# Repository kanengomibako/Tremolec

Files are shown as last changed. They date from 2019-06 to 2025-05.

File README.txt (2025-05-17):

Tremolec

トレモロを周波数帯域別にかけるというエフェクターです。
製作記事→https://kanengomibako.github.io/pages/00243.html

＜パーツリスト＞
2	220p	[1608] C3, C4
1	4.7n	C10　※DIPフィルムコンデンサ
2	22n	C6, C13　※DIPフィルムコンデンサ
1	47n	C14　※DIPフィルムコンデンサ
1	100n	[3225] C1　※PMLCAP
2	100n	C11, C12　※DIPフィルムコンデンサ
10	100n	[2012] C19, C20, C21, C22, C24, C25, C26, C27, C28, C29
2	330n	C5, C8　※DIPフィルムコンデンサ
2	10u	C2, C15　※SMD電解コンデンサ（直径5mm）
4	10u	[3216] C16, C17, C23, C30
1	100u	C18　※DIP電解コンデンサ
		
1	220R	[2012] R25
2	470R	[2012] R14, R22
8	1k	[2012] R3, R8, R9, R15, R17, R18, R23, R24
5	4.7k	[2012] R5, R7, R10, R30, R32
6	10k	[2012] R4, R6, R31, R33, R34, R35
11	100k	[2012] R11, R12, R13, R16, R19, R20, R21, R26, R27, R28, R29
1	1M	[2012] R2
1	2.2M	[1608] R1
		
5	10kB	RV1, RV2, RV3, RV4, RV5
		
6	LCR0202	U4, U5, U6, U7, U8, U9
		
1	1N4007	D1
2	LED	D2, D3
		
3	OPA1678IDR	U1, U2, U3
1	LP2950L-3.3V	U10
1	LP2950L-5.0V	U11
1	ATmega328P-AU	U12
3	MCP4922-E/SL	U13, U14, U15
		
1	SPST Momentary Push Switch	SW1　※タップスイッチ
1	SPDT ON-ON Toggle Switch	SW2
1	SPDT ON-OFF-ON Toggle Switch	SW3
1	3PDT ON-ON Push Switch	※トゥルーバイパス用スイッチ

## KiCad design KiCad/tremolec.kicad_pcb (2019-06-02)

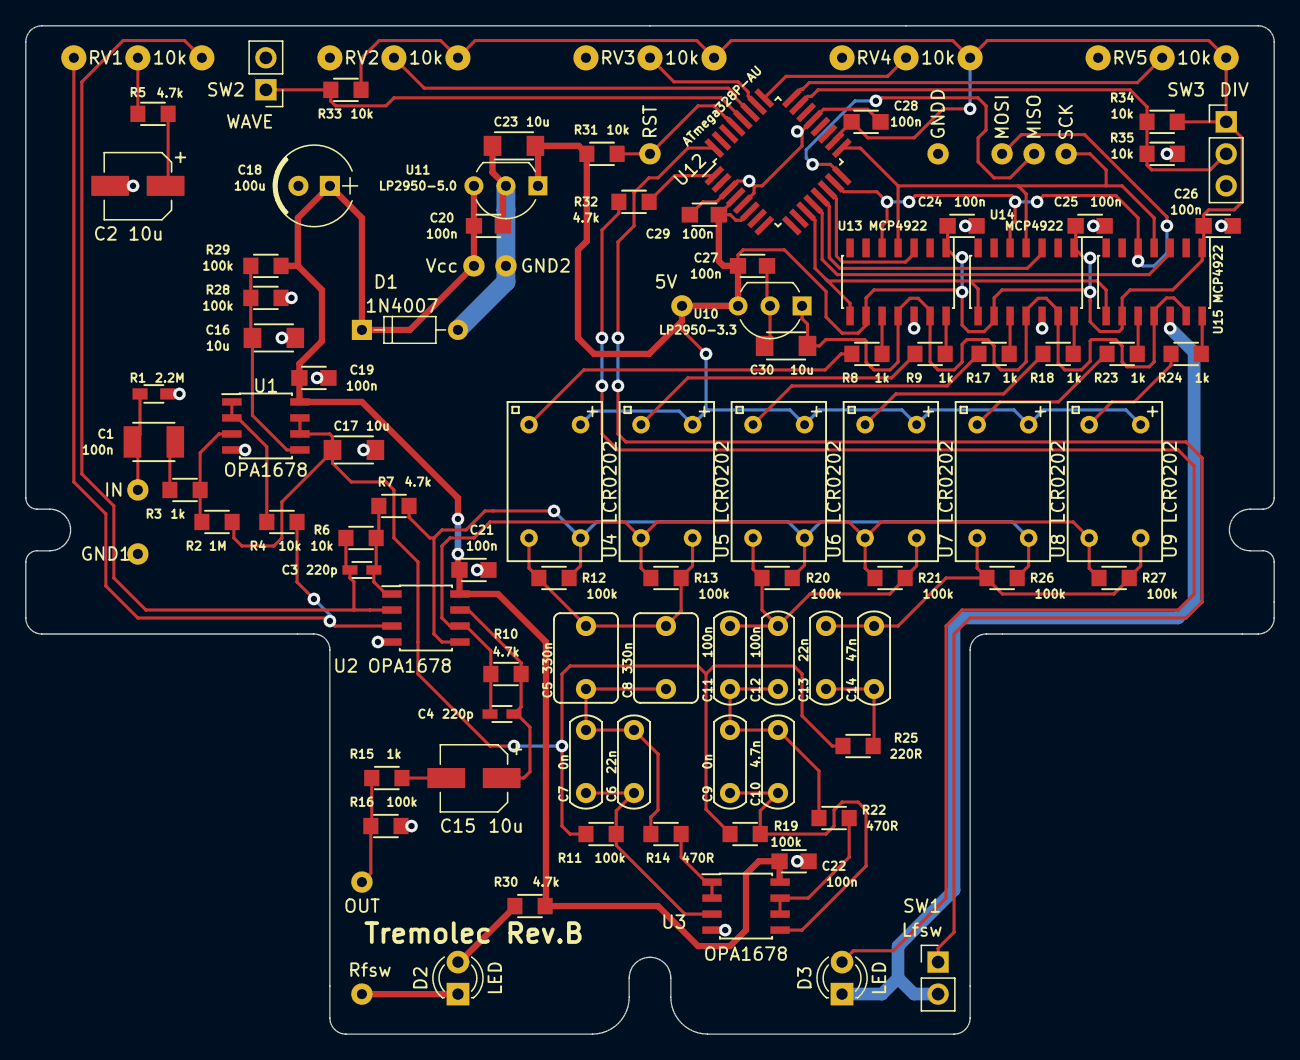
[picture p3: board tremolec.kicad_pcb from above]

Board: 2 copper layers, 99.1 x 80.0 mm, 103 parts (0 on the bottom side), 61 nets.

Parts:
C1: 100n; my_C_3225(1210)_HandSoldering
C2, C15: 10u; CP_Elec_5x5.3
C3, C4: 220p; my_C_1608(0603)_HandSoldering
C5, C8: 330n; my_C_Rect2_P5.00mm
C6, C13: 22n; my_C_Rect1_P5.00mm
C7, C9: 0n; my_C_Rect1_P5.00mm
C10: 4.7n; my_C_Rect1_P5.00mm
C11, C12: 100n; my_C_Rect1_P5.00mm
C14: 47n; my_C_Rect1_P5.00mm
C16, C17, C23, C30: 10u; my_C_3216(1206)_HandSoldering
C18: 100u; my_C_D6.3mm_P2.50mm
C19, C20, C21, C22, C24, C25, C26, C27, C28, C29: 100n; my_C_2012(0805)_HandSoldering
D1: 1N4007; D_DO-35_SOD27_P7.62mm_Horizontal
D2, D3: LED; LED_D3.0mm
J1: IN; my_SmallPad_0-8mmDrill
J2: OUT; my_SmallPad_0-8mmDrill
J3: Rfsw; my_SmallPad_0-8mmDrill
J4: MISO; my_SmallPad_0-8mmDrill
J5: MOSI; my_SmallPad_0-8mmDrill
J6: SCK; my_SmallPad_0-8mmDrill
J7: RST; my_SmallPad_0-8mmDrill
J8: Vcc; my_SmallPad_0-8mmDrill
J9: GND1; my_SmallPad_0-8mmDrill
J10: GND2; my_SmallPad_0-8mmDrill
R1: 2.2M; my_R_1608(0603)_HandSoldering
R2: 1M; my_R_2012(0805)_HandSoldering
R3, R8, R9, R15, R17, R18, R23, R24: 1k; my_R_2012(0805)_HandSoldering
R4, R6, R31, R33, R34, R35: 10k; my_R_2012(0805)_HandSoldering
R5, R7, R10, R30, R32: 4.7k; my_R_2012(0805)_HandSoldering
R11, R12, R13, R16, R19, R20, R21, R26, R27, R28, R29: 100k; my_R_2012(0805)_HandSoldering
R14, R22: 470R; my_R_2012(0805)_HandSoldering
R25: 220R; my_R_2012(0805)_HandSoldering
RV1, RV2, RV3, RV4, RV5: 10k; my_pot
SW1: Lfsw; Pin_Header_Straight_1x02_Pitch2.54mm
SW2: WAVE; Pin_Header_Straight_1x02_Pitch2.54mm
SW3: DIV; Pin_Header_Straight_1x03_Pitch2.54mm
TP2: GNDD; my_SmallPad_0-8mmDrill
TP3: 5V; my_SmallPad_0-8mmDrill
U1, U2, U3: OPA1678; SOIC-8_3.9x4.9mm_Pitch1.27mm
U4, U5, U6, U7, U8, U9: LCR0202
U10: LP2950-3.3; TO-92_Inline_Wide
U11: LP2950-5.0; TO-92_Inline_Wide
U12: ATmega328P-AU; my_TQFP-32
U13, U14, U15: MCP4922; SOIC-14_3.9x8.7mm_Pitch1.27mm

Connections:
+3V3: C30.1, U10.1, U13.11, U13.13, U14.11, U14.13, U15.11, U15.13
+5V: C23.1, C24.1, C25.1, C26.1, C27.1, C28.1, C29.1, R31.1, R33.1, R34.1, RV2.3, RV3.3, RV4.3, RV5.3, SW3.1, TP3.1, U4.1, U5.1, U6.1, U7.1, U8.1, U9.1, U10.3, U11.1, U12.4, U12.6, U12.18, U13.1, U13.9, U14.1, U14.9, U15.1, U15.9
+9V: C18.1, C19.1, C20.1, C21.1, C22.1, D1.1, J8.1, R28.1, R30.2, U1.8, U2.8, U3.8, U11.3
/BASS+: R9.2, U13.14
/BASS-: R8.2, U13.10
/BIAS: C17.1, R2.2, R11.2, R19.2, R25.2, U1.6, U1.7
/LDAC: U12.11, U13.8, U14.8, U15.8
/MID+: R18.2, U14.14
/MID-: R17.2, U14.10
/MOSI: J5.1, U12.15, U13.5, U14.5, U15.5
/RV2: RV2.2, U12.27
/RV3: RV3.2, U12.26
/RV4: RV4.2, U12.25
/RV5: RV5.2, U12.24
/SCK: J6.1, U12.17, U13.4, U14.4, U15.4
/SS1: U12.14, U13.3
/SS2: U12.13, U14.3
/SS3: U12.12, U15.3
/SW2: R33.2, SW2.1, U12.28
/SW3: R34.2, R35.2, SW3.2, U12.23
/TRE+: R24.2, U15.14
/TRE-: R23.2, U15.10
GNDA: C2.2, C16.2, C17.2, C18.2, C19.2, C20.2, C21.2, C22.2, C23.2, C24.2, C25.2, C26.2, C27.2, C28.2, C29.2, C30.2, D1.2, D3.1, J9.1, J10.1, R1.2, R16.2, R29.2, R35.1, RV2.1, RV3.1, RV4.1, RV5.1, SW1.2, SW2.2, SW3.3, TP2.1, U1.4, U2.4, U3.4, U10.2, U11.2, U12.3, U12.5, U12.21, U13.12, U14.12, U15.12
unnamed: C1.1, R3.2
unnamed: C1.2, J1.1, R1.1
unnamed: C2.1, R5.2
unnamed: C3.1, R6.1, R7.2, U2.1
unnamed: C3.2, R6.2, RV1.3, U2.2
unnamed: C4.2, R10.2, R13.2, R21.2, R27.2, U2.6, U5.3, U7.3, U9.3
unnamed: C5.1, C8.1, R12.2, R13.1, U4.3, U5.4
unnamed: C5.2, C6.1, C7.1, C8.2, R14.1
unnamed: C6.2, C7.2, R11.1, U3.3
unnamed: C9.1, C10.1, C11.2, C12.2, R22.1
unnamed: C9.2, C10.2, R19.1, U3.5
unnamed: C11.1, C12.1, R20.2, R21.1, U6.3, U7.4
unnamed: C13.1, C14.1, R26.2, R27.1, U8.3, U9.4
unnamed: C13.2, C14.2, R25.1
unnamed: C4.1, C15.1, R10.1, U2.7
unnamed: C15.2, R15.2
unnamed: C16.1, R28.2, R29.1, U1.5
unnamed: D2.1, J3.1
unnamed: D2.2, R30.1
unnamed: D3.2, R32.1
unnamed: J2.1, R15.1, R16.1
unnamed: J4.1, U12.16
unnamed: J7.1, R31.2, U12.29
unnamed: R2.1, R3.1, U1.3
unnamed: R4.1, RV1.1, U2.3
unnamed: R4.2, U1.1, U1.2
unnamed: R5.1, RV1.2
unnamed: R8.1, U4.2
unnamed: R9.1, U5.2
unnamed: R7.1, R12.1, R20.1, R26.1, U2.5, U4.4, U6.4, U8.4
unnamed: R14.2, U3.1, U3.2
unnamed: R17.1, U6.2
unnamed: R18.1, U7.2
unnamed: R22.2, U3.6, U3.7
unnamed: R23.1, U8.2
unnamed: R24.1, U9.2
unnamed: R32.2, U12.1
unnamed: SW1.1, U12.32

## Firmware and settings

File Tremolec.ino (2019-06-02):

#include <SPI.h>

// ピン設定 実際は高速処理するため該当レジスタを直接変更
const byte swPin = 2;  // タップスイッチ
const byte ledPin = 3; // PD3 周期表示用LED
const byte SS1 = 10;   // PB2 MCP4922 Low
const byte SS2 = 9;    // PB1 MCP4922 Mid
const byte SS3 = 8;    // PB0 MCP4922 Treble
const byte LDAC = 7;   // PD7 MCP4922 電圧出力作動ピン

// LFO1周期を500分割 0.002周期経過するごとに電圧値を変更する
volatile int pwmCount = 0;  // LFO用カウンタ  0〜499
volatile int waveCount = 0; // 波形用カウンタ 0～125

volatile unsigned long timeCount = 0; // タップ時間取得用カウンタ
unsigned long tapTime = 0;            // タップ間隔時間 us
unsigned long timeTemp = 0;           // タップ間隔時間一時保存用
unsigned long swCount = 0;            // タップスイッチ用カウンタ

byte adcNum = 0; // ADC番号（配列の添字）Bass0 Mid1 Tre2 Wave3 Div4 Rate5
const byte adcPinArray[6] = {16, 17, 18, 19, 14, 15}; // ADCピン設定
unsigned int oldAdcValue[6] = {2000, 2001, 2002, 2003, 2004, 2005}; // 旧ADC値
unsigned int newAdcValue[6] = {1110, 1111, 1112, 1113, 1114, 1115}; // 新ADC値

unsigned int dacArray[626]; // 電圧値配列 626段階 セットアップ時計算
unsigned long dacDepth[3] = {0, 1, 2}; // 電圧値配列添字部分の倍率
volatile unsigned int dacValueA[3] = {4001, 4002, 4003}; // 出力電圧値 増幅側
volatile unsigned int dacValueB[3] = {4011, 4012, 4013}; // 出力電圧値 減衰側
byte waveAmp = 1;   // 三角波→矩形波変換 増幅率
const byte SQ = 12; // 上記増幅率設定値
byte tapDiv = 1;    // タップ時間分割値
//const float rateAdj = 1.000; // 周期補正 実測して設定→不要

const unsigned int ledOnTime = 40000; // 周期表示LED点灯時間設定値 us
unsigned int ledOffCount = 250;       // 上記LEDが消灯するカウンタ値

void setup() {
  TIMSK0 = 0; // Timer0割り込み停止 安定動作のため割り込みはTimer1のみ

  // 電圧値の配列を計算 指数カーブ
  for (int i = 0; i <= 625; i++) {
    dacArray[i] = 4141 - 46 * exp(0.0072 * i);
  }

  pinMode(swPin, INPUT_PULLUP);
  pinMode(ledPin, OUTPUT);
  pinMode(SS1, OUTPUT);
  pinMode(SS2, OUTPUT);
  pinMode(SS3, OUTPUT);
  pinMode(LDAC, OUTPUT);

  SPI.begin();
  SPI.beginTransaction(SPISettings(8000000, MSBFIRST, SPI_MODE0)); // SPI 8MHz

  // Timer1 電圧値変更間隔時間管理・タップ時間計測
  TCCR1A = 0b00000000;     // Timer1 CTCモード
  TCCR1B = 0b00001010;     // Timer1 CTCモード クロック8分周
  OCR1A = 100;             // Timer1 比較Aの値 = 割り込み間隔 us
  TIMSK1 |= (1 << OCIE1A); // Timer1 比較A割り込み許可
}

// LFO（Timer1 比較A割り込み）-----------------------------------------------------
ISR(TIMER1_COMPA_vect) {
  timeCount++; // タップ時間取得用カウンタ
  PORTD &= ~_BV(7); // LDAC LOW (最初に電圧出力)
  PORTD |= _BV(7);  // LDAC HIGH
  if (pwmCount == 500) pwmCount = 0; // 0〜499 ループ
  if (pwmCount <= 125) {         // 三角波 増幅側上昇
    waveCount = waveAmp * pwmCount;  // 三角波を増幅後、
    waveCount = min(waveCount, 125); // クリップし矩形波とする
    dacA(waveCount);
  } else if (pwmCount <= 250)  { // 三角波 増幅側下降
    waveCount = waveAmp * (250 - pwmCount);
    waveCount = min(waveCount, 125);
    dacA(waveCount);
  } else if  (pwmCount <= 375) { // 三角波 減衰側上昇
    waveCount = waveAmp * (pwmCount - 250);
    waveCount = min(waveCount, 125);
    dacB(waveCount);
  } else {                       // 三角波 減衰側下降
    waveCount = waveAmp * (500 - pwmCount);
    waveCount = min(waveCount, 125);
    dacB(waveCount);
  }
  if (pwmCount == 125) PORTD |= _BV(3); // 周期表示LED点灯
  if (pwmCount == ledOffCount) PORTD &= ~_BV(3); // 消灯
  pwmCount++;
}

void loop() {
  // タップテンポ -----------------------------------------------------------------
  if (digitalRead(swPin) == LOW) {
    swCount++;
    if (swCount == 50) { // チャタリング対策 数msスイッチ押下で検出
      // 前回スイッチ検出から経過した時間を記録
      tapTime = timeTemp + timeCount * OCR1A  + TCNT1;
      TCNT1 = 0; // 経過時間をリセット
      timeTemp = 0;
      timeCount = 0;
      pwmCount = 124; // 増幅最大の点にリセット
      if ( 200000 < tapTime && tapTime < 2100000) { // 周期制限 0.2秒～2.1秒
        // タップ間隔を電圧値変更間隔時間へ換算（Divスイッチ加味）
        OCR1A = tapTime * 0.002 / tapDiv;
        // どの周期でも周期表示LEDの点灯時間が同程度になるよう計算
        ledOffCount = 125 + ledOnTime / OCR1A;
      }
    }
  }
  else swCount = 0;

  // ADC --------------------------------------------------------------------------
  adcNum++;
  if (adcNum == 6) adcNum = 0; // 0〜5 ループ
  newAdcValue[adcNum] = analogRead(adcPinArray[adcNum]); // 読取値が4以上変化で変更
  if (abs(newAdcValue[adcNum] - oldAdcValue[adcNum]) >= 4) {
    if (adcNum <= 2) { // Depth 0〜640  160までは急な変化
      if (newAdcValue[adcNum] < 100) dacDepth[adcNum] = 1.6 * newAdcValue[adcNum];
      else dacDepth[adcNum] = 0.5201 * newAdcValue[adcNum] + 108;
    } else if (adcNum == 3) { // Wave 1 or SQ 矩形波変換増幅率
      if (newAdcValue[adcNum] < 500) waveAmp = 1;
      else waveAmp = SQ;
    } else if (adcNum == 4) { // Div 1〜3 タップ時間分割値
      tapDiv = 0.0029 * newAdcValue[adcNum] + 1;
    } else if (adcNum == 5) { // Rate 4004〜133 電圧値変更間隔時間
      // Rate変更前から経過した時間を記録
      timeTemp = timeTemp + timeCount * OCR1A  + TCNT1;
      TCNT1 = 0; // 経過時間をリセット
      timeCount = 0;
      // Rate計算 指数カーブ
      OCR1A = 73 * exp(0.0039 * (1023 - newAdcValue[adcNum])) + 60;
      // どの周期でも周期表示LEDの点灯時間が同程度になるよう計算
      ledOffCount = 125 + ledOnTime / OCR1A;
    }
    oldAdcValue[adcNum] = newAdcValue[adcNum];
  }
}

// 電圧値設定 A：増幅側 B：減衰側--------------------------------------------------
void dacA(int w) { // w：waveCount 波形用カウンタ
  // w(0〜125)にDepth(0〜640)をかけ128で割ったものが電圧値配列の添字(0〜625)
  dacValueA[0] = dacArray[(dacDepth[0] * w) >> 7];
  dacValueA[1] = dacArray[(dacDepth[1] * w) >> 7];
  dacValueA[2] = dacArray[(dacDepth[2] * w) >> 7];
  PORTB &= ~_BV(2); // SS1(PB2) LOW
  SPI.transfer((dacValueA[0] >> 8) | 0x30); // 0x30=0b00110000 A出力 バッファなし
  SPI.transfer(dacValueA[0] & 0xff);        // ゲイン1倍 シャットダウンなし
  PORTB |= _BV(2);  // SS1(PB2) HIGH
  PORTB &= ~_BV(1); // SS2(PB1)
  SPI.transfer((dacValueA[1] >> 8) | 0x30);
  SPI.transfer(dacValueA[1] & 0xff);
  PORTB |= _BV(1);
  PORTB &= ~_BV(0); // SS3(PB0)
  SPI.transfer((dacValueA[2] >> 8) | 0x30);
  SPI.transfer(dacValueA[2] & 0xff);
  PORTB |= _BV(0);
}

void dacB(int w) {
  dacValueB[0] = dacArray[(dacDepth[0] * w) >> 7];
  dacValueB[1] = dacArray[(dacDepth[1] * w) >> 7];
  dacValueB[2] = dacArray[(dacDepth[2] * w) >> 7];
  PORTB &= ~_BV(2);
  SPI.transfer((dacValueB[0] >> 8) | 0xb0); // 0xb0=0b10110000 B出力
  SPI.transfer(dacValueB[0] & 0xff);
  PORTB |= _BV(2);
  PORTB &= ~_BV(1);
  SPI.transfer((dacValueB[1] >> 8) | 0xb0);
  SPI.transfer(dacValueB[1] & 0xff);
  PORTB |= _BV(1);
  PORTB &= ~_BV(0);
  SPI.transfer((dacValueB[2] >> 8) | 0xb0);
  SPI.transfer(dacValueB[2] & 0xff);
  PORTB |= _BV(0);
}
